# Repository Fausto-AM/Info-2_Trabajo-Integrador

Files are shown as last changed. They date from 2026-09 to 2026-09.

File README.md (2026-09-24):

# Trabajo Práctico Integrador - Máquinas de Estado

Repositorio personal para la entrega del Trabajo Práctico Integrador de Informática II para la UTNFRA.

## Profesores

- Ing. Gustavo Viard.
- Mg. Ing. Damian Ruben Corbalan.

## Generador de Funciones con ESP32

### Resumen

El proyecto consiste en el diseño e implementación de un generador de funciones digital basado en un microcontrolador ESP32-WROOM.

El sistema permite seleccionar la forma de onda y modificar sus principales parámetros mediante un único encoder rotativo con pulsador. La información correspondiente al estado del generador, la función seleccionada y los parámetros configurables se presenta en una pantalla OLED SSD1306 de 128 × 64 píxeles.

La señal de salida es generada digitalmente mediante tablas de consulta (_Look-Up Tables_ [LUT]) y posteriormente convertida a una señal analógica mediante el DAC interno del ESP32. La generación de muestras se realiza a una frecuencia de muestreo de 40 kHz.

El firmware se encuentra organizado en módulos independientes y utiliza una máquina de estados finitos para gestionar la interfaz de usuario y los diferentes modos de operación del generador.

### Objetivos

- Implementar un generador de funciones digital utilizando el DAC interno del ESP32.
- Generar diferentes formas de onda: seno, cuadrada, triangular y sierra.
- Permitir la modificación de frecuencia, amplitud, offset y ciclo de trabajo.
- Permitir la modificación de los parámetros mientras la señal se encuentra siendo generada.
- Implementar una interfaz de usuario utilizando únicamente un encoder rotativo con pulsador.
- Visualizar el estado del sistema y los parámetros configurables mediante una pantalla OLED.
- Implementar una máquina de estados finitos que gestione la navegación y las acciones del usuario.
- Separar las diferentes funciones del firmware en módulos independientes.
- Generar las muestras de salida mediante una frecuencia de muestreo fija de 40 kHz.

### Diseño de la FSM

La interfaz de usuario se implementa mediante una máquina de estados finitos (FSM) contenida en `generator.c` y `generator.h`.

Los eventos producidos por el encoder son:

- `ENC_CW`: giro horario.
- `ENC_CCW`: giro antihorario.
- `ENC_SHORT_PRESS`: pulsación corta.
- `ENC_LONG_PRESS`: pulsación larga.

#### Estados

- `STATE_STANDBY`

    Es el estado inicial de operación del generador.

    La salida se encuentra detenida y el usuario puede desplazarse mediante el encoder entre las siguientes opciones:

    * Parámetros
    * Función
    * RUN

    Una pulsación corta confirma la opción seleccionada.

    Al seleccionar _RUN_, el sistema pasa a `STATE_GENERATING`.

- `STATE_GENERATING`

    En este estado el generador se encuentra funcionando y el DAC recibe las muestras generadas.

    El menú principal pasa a mostrar:

    * Parámetros
    * Función
    * STOP

    Desde este estado también es posible ingresar a los menús de parámetros y selección de función sin detener la generación de la señal.

    Al seleccionar _STOP_, el sistema vuelve a `STATE_STANDBY`.

- `STATE_SELECT_PARAM`

    Permite seleccionar uno de los cuatro parámetros configurables:

    * Frecuencia
    * Amplitud
    * Offset
    * Duty

    Una pulsación corta sobre un parámetro lleva a `STATE_EDIT_PARAM`.

    Una pulsación larga abandona el menú y retorna al estado desde el cual se ingresó.

- `STATE_EDIT_PARAM`

    Permite modificar el parámetro seleccionado mediante el giro del encoder.

    Cada parámetro posee:

    * un valor actual;
    * un límite mínimo;
    * un límite máximo;
    * un tamaño de paso;
    * una función setter encargada de aplicar el nuevo valor.

    Los valores se limitan automáticamente a los rangos definidos en config.h.

    Una pulsación corta o larga finaliza la edición y retorna a `STATE_SELECT_PARAM`.

- `STATE_SELECT_FUNC`

    Permite seleccionar la forma de onda utilizada por el generador:

    * Seno
    * Cuadrada
    * Triangular
    * Sierra

    Una pulsación corta aplica inmediatamente la función seleccionada. Esto permite recorrer las diferentes formas de onda y observar el cambio sin abandonar el menú.

    Una pulsación larga retorna al estado desde el cual se ingresó.

### Descripción de archivos

| Archivo | Responsabilidad |
|---|---|
| main.c | Punto de entrada de la aplicación. Inicializa el sistema y ejecuta el bucle principal de _polling_.
| sys.c/.h | Inicialización general de los módulos y procesamiento de eventos del sistema.
| generator.c/.h | Implementación de la máquina de estados, navegación de menús, selección de parámetros y control `RUN/STOP`.
| encoder.c/.h | Lectura del encoder y del pulsador. Genera los eventos utilizados por la FSM.
| display.c/.h | Control y actualización de la pantalla OLED mediante u8g2 e I2C.
| waveform.c/.h | Generación de las LUT, selección de formas de onda, acumulador de fase y cálculo de muestras.
| dac.c/.h | Abstracción del DAC interno del ESP32 mediante dac_oneshot.
| sample_timer.c/.h | Temporización de la generación de muestras mediante `esp_timer`.
| config.h | Configuración de GPIO, límites de parámetros, frecuencia de muestreo y constantes del sistema.

### Diagrama de la Máquina de Estado

Diagrama de la Máquina de Estado

### Esquemático

Esquemático

### PCB Finalizado

PCB

### Proyecto Funcionando

Proyecto en Funcionamiento

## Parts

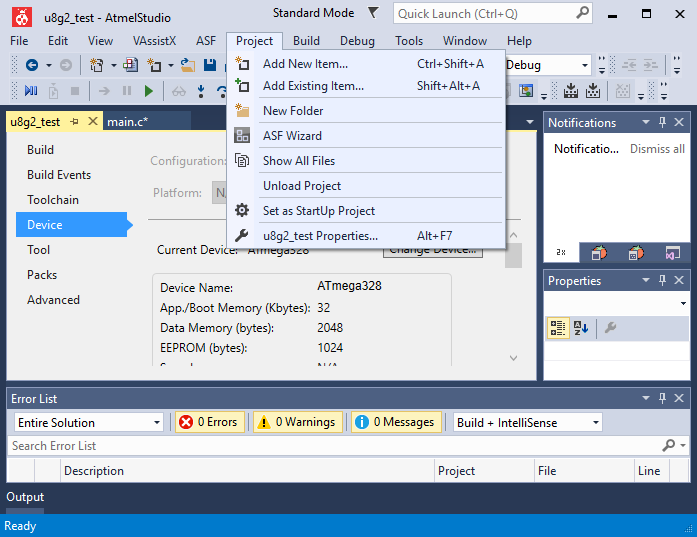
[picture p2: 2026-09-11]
Signal_Generator/components/u8g2/sys/avr/as7/as7_006.png

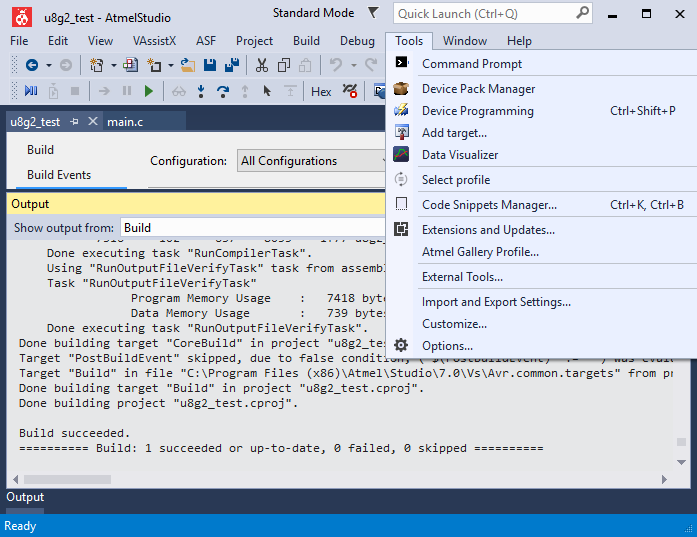
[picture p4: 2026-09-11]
Signal_Generator/components/u8g2/sys/avr/as7/as7_012.png

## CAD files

Signal_Generator/components/u8g2/sys/arduino/u8g2_full_buffer/SwitchBox/board.dxf
60
40
52
8
24
80
30
32
25
100
190
4
12
6
14

Signal_Generator/components/u8g2/sys/arm/stm32l031x6/clock_2.dxf
65
Draufsicht
Vorderansicht
von unten
von rechts
von links
14
30
32
35
75
55
10
12
16
11
22
34
28
29
18
93
19
43
15
68
60
57
150
Holzbohrer: 2.5, 8, 10, 12, 16, 32mm
8
7
6
2.5mm

Signal_Generator/components/u8g2/sys/arm/stm32l031x6/clock.dxf
65
32
28
16
Draufsicht
Vorderansicht
von unten
von rechts
von links
14
6
45
60
30
20
8
35
75
55
10
12

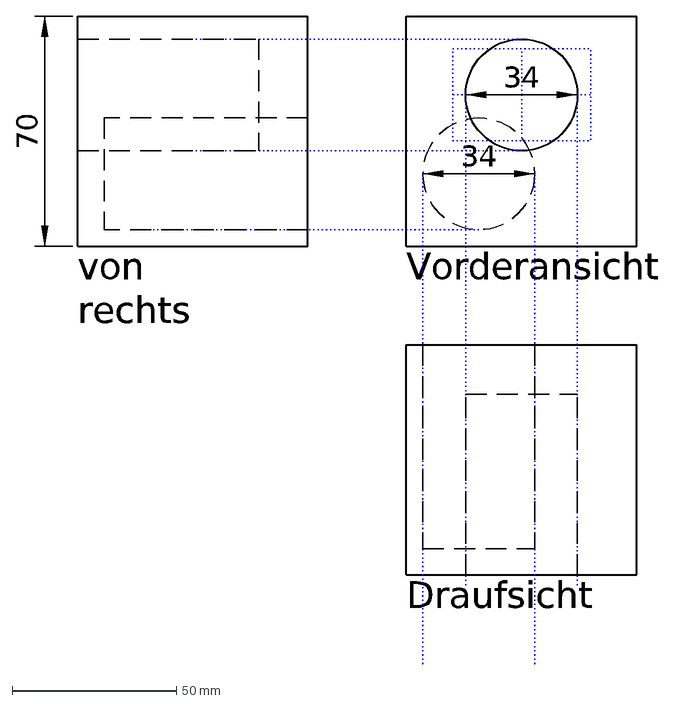
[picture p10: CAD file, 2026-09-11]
Signal_Generator/components/u8g2/sys/arm/stm32l031x6/clock_cube.dxf
Draufsicht
Vorderansicht
von rechts
70
34

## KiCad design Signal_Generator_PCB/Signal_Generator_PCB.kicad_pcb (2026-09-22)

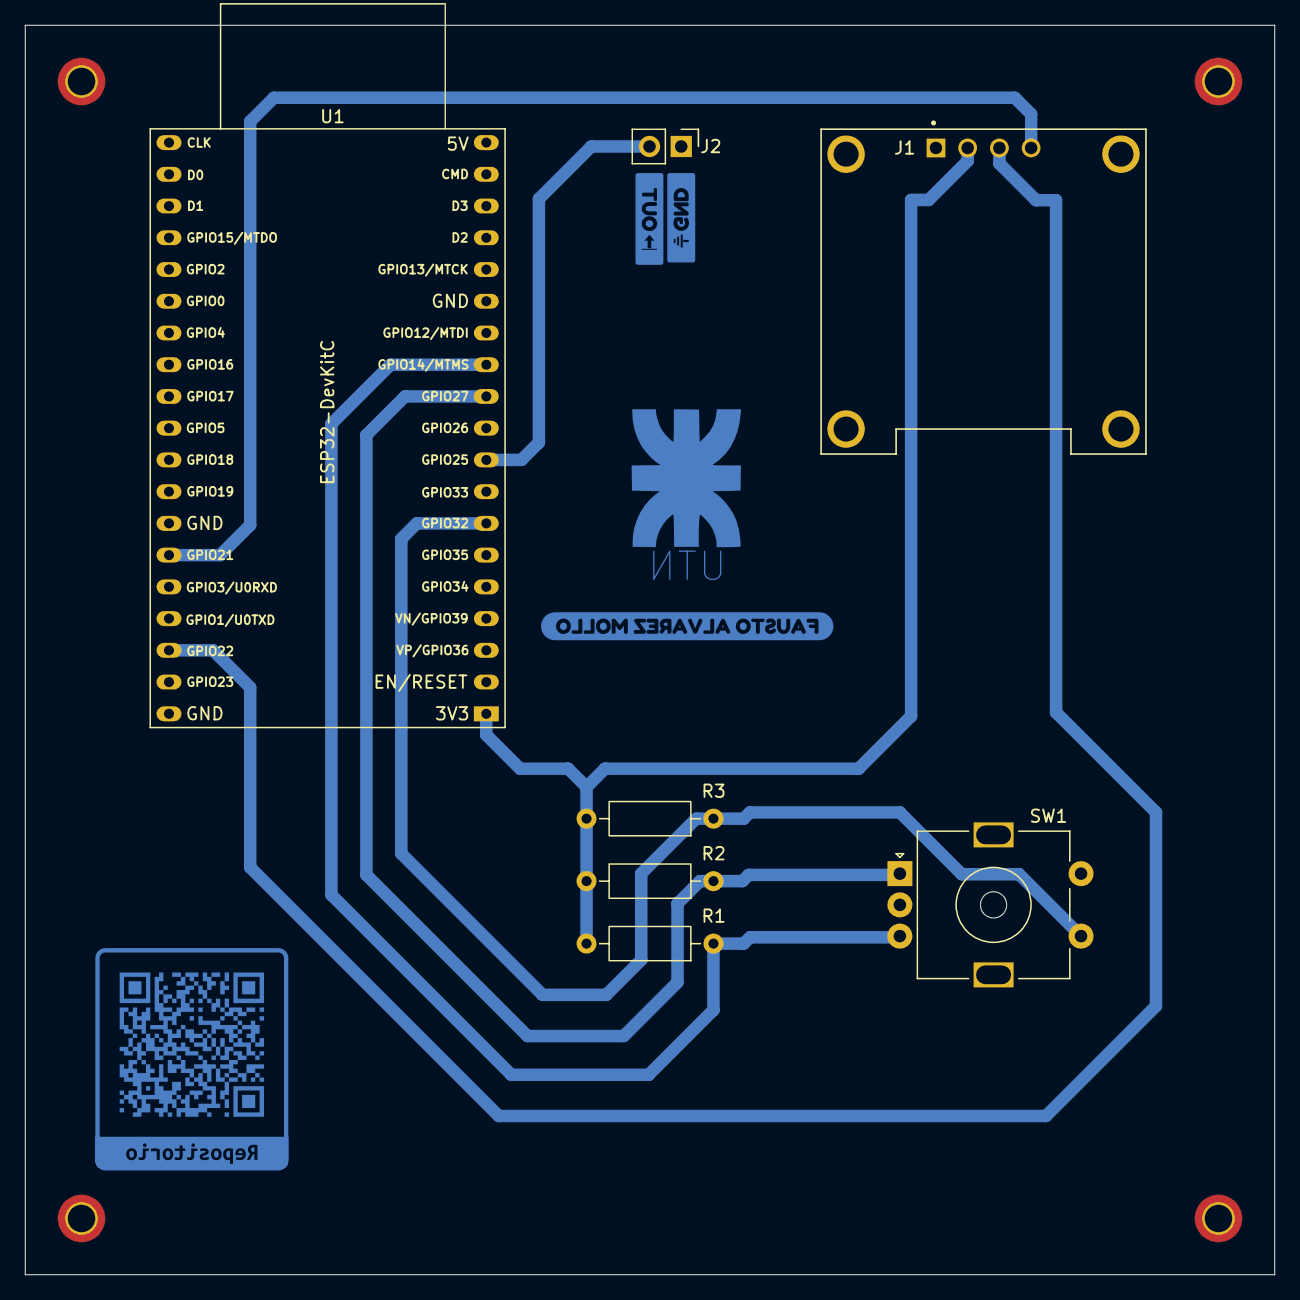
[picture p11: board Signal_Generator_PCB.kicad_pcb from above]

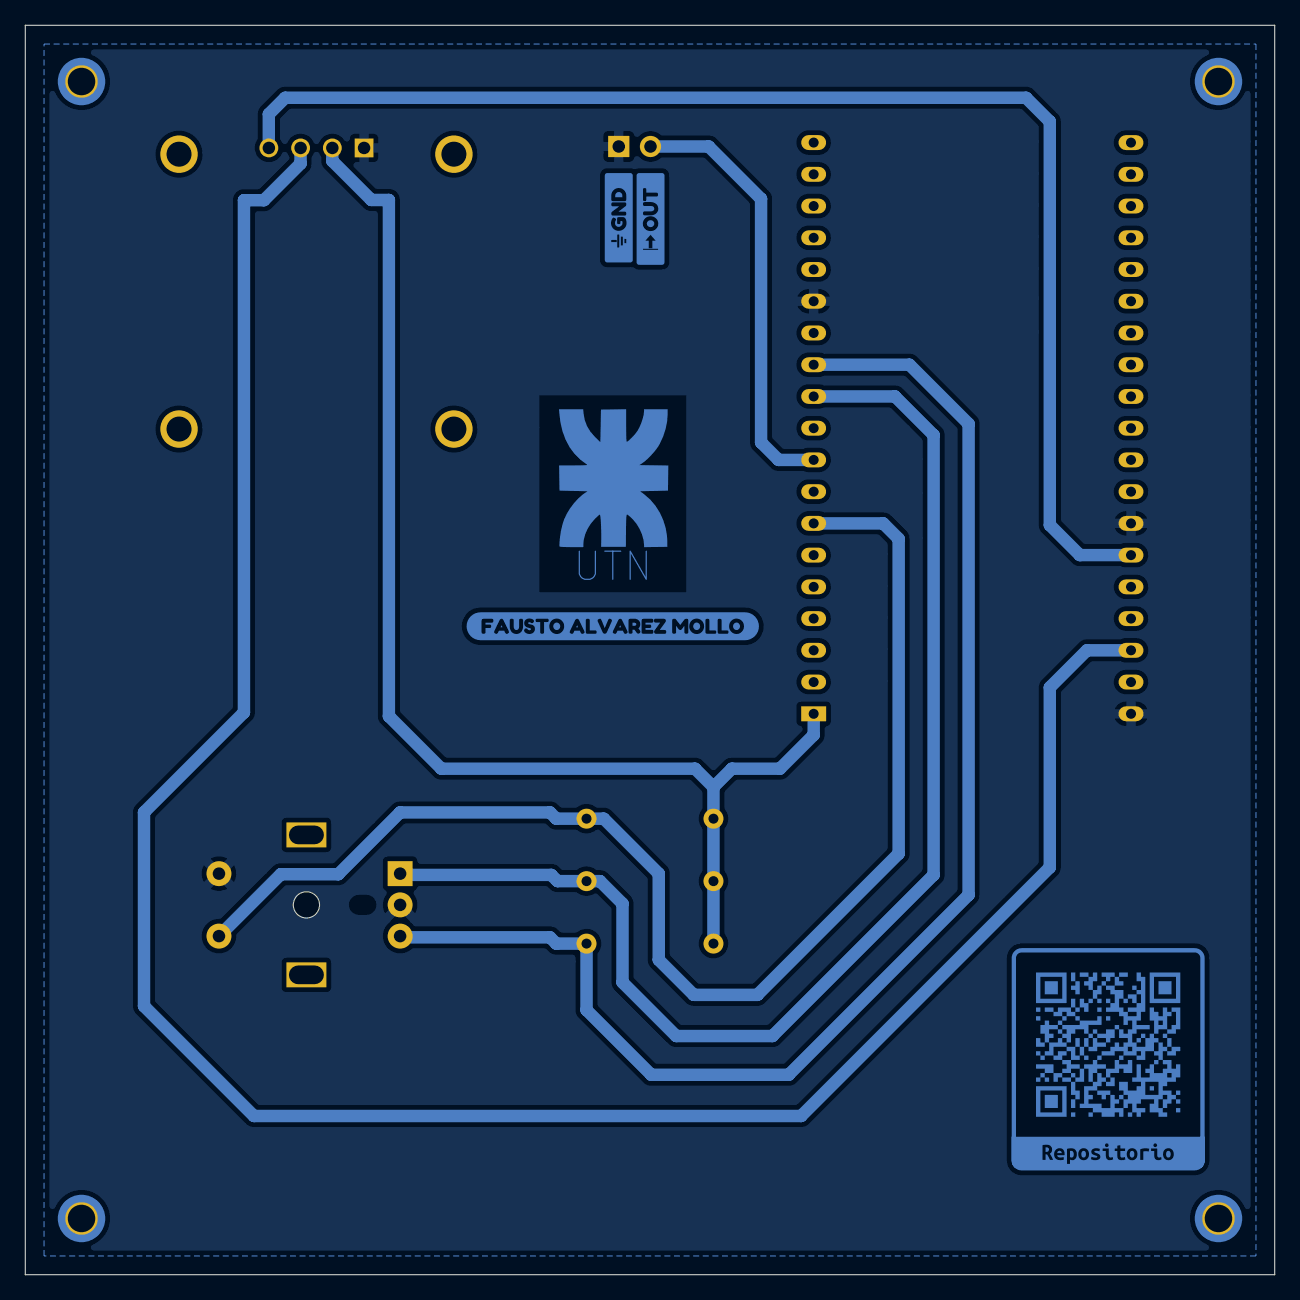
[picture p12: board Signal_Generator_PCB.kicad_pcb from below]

Board: 2 copper layers, 100.0 x 100.0 mm, 11 parts (4 on the bottom side), 8 nets.

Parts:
J1: OLED Screen; MODULE_DM-OLED096-636
J2: Conn_01x02; PinHeader_1x02_P2.54mm_Vertical
R1, R2, R3: 10k; R_Axial_DIN0207_L6.3mm_D2.5mm_P10.16mm_Horizontal
SW1: Rotary Encoder with Switch; RotaryEncoder_Alps_EC11E-Switch_Vertical_H20mm_MountingHoles
U1: ESP32-DevKitC
kobee-studio-6AAF5AC9: Kobee Studio; kobee-studio-6AAF5ABC
kobee-studio-6AAF54B1: Kobee Studio; kobee-studio-6AAF52F9
kobee-studio-6AAF59F9: Kobee Studio; kobee-studio-6AAF59EB
kobee-studio-6AAF543E: Kobee Studio; kobee-studio-6AAF5432

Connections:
+3.3V: J1.2 (VDD), R1.2, R2.2, R3.2, U1.1 (3V3)
/GPIO14: R1.1, SW1.B, U1.12 (MTMS/GPIO14/ADC2_CH6)
/GPIO21: J1.4 (SDA), U1.33 (GPIO21)
/GPIO22: J1.3 (SCK), U1.36 (GPIO22)
/GPIO25: J2.1, U1.9 (DAC_1/ADC2_CH8/GPIO25)
/GPIO27: R2.1, SW1.A, U1.11 (ADC2_CH7/GPIO27)
/GPIO32: R3.1, SW1.S1, U1.7 (32K_XP/GPIO32/ADC1_CH4)
GND: J1.1 (GND), J2.2, SW1.C, SW1.S2, U1.14 (GND), U1.32 (GND), U1.38 (GND)

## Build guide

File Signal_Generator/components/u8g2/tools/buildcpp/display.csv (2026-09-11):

# 1. device name
# 2. pinset
# 3. constructor name w/o prefix
u8x8_d_ssd1306_128x64_noname | 4WSWSPI | SSD1306_128X64_4W_SW_SPI
u8x8_d_ssd1306_128x64_noname | 4WHWSPI | SSD1306_128X64_4W_HW_SPI
u8x8_d_ssd1306_128x64_noname | 3WSWSPI | SSD1306_128X64_3W_SW_SPI
u8x8_d_ssd1306_128x64_noname | SSDSWI2C | SSD1306_128X64_SW_I2C
u8x8_d_ssd1306_128x64_noname | 6800 | SSD1306_128X64_6800
u8x8_d_ssd1306_128x64_noname | 8080 | SSD1306_128X64_8080

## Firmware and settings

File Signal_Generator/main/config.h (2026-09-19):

#ifndef CONFIG_H
#define CONFIG_H

#include <stdint.h>

// GPIO definitions
#define PIN_SDA       21
#define PIN_SCL       22
#define PIN_DAC       25
#define PIN_ENC_A     27
#define PIN_ENC_B     14
#define PIN_ENC_BTTN  32


// OLED Display parameters
#define OLED_ADDR     0x3C
#define OLED_WIDTH    128
#define OLED_HEIGHT   64


// Waveform generation parameters
#define LUT_SIZE      256
#define SAMPLE_RATE   40000.0f
#define BASE_FREQ     1000.0f
#define BASE_AMP_VPP  1.65f
#define BASE_OFFSET   0.0f
#define BASE_DUTY     0.5f
#define MIN_FREQ      1.0f
#define MAX_FREQ      5000.0f
#define MIN_AMP_VPP   0.1f
#define MAX_AMP_VPP   3.3f
#define MIN_OFFSET   -3.0f
#define MAX_OFFSET    3.3f
#define MIN_DUTY      0.0f
#define MAX_DUTY      1.0f

// General Parameters
#define DAC_MAX_VALUE 255
#define BUTTON_LONG_PRESS_MS 500
#define BUTTON_DEBOUNCE_MS   25
#define ENCODER_STEPS_PER_DETENT  2

#endif

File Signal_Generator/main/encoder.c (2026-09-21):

#include "encoder.h"
#include "esp_timer.h"
#include "esp_log.h"

static const char *TAG = "ENCODER";

static volatile int enc_count = 0;

static volatile uint8_t last_ab_state = 0;

static int last_count = 0;

static uint64_t btn_press_start = 0;

static int btn_pressed = 0;
static int raw_pressed_prev = 0;
static uint64_t raw_change_ms = 0;
static const int8_t qdec_table[16] = {
     0, -1,  1,  0,
     1,  0,  0, -1,
    -1,  0,  0,  1,
     0,  1, -1,  0
};

void IRAM_ATTR encoder_isr(void *arg)
{
    (void)arg;

    uint8_t a = (uint8_t)gpio_get_level(PIN_ENC_A);
    uint8_t b = (uint8_t)gpio_get_level(PIN_ENC_B);

    uint8_t new_state = (a << 1) | b;

    uint8_t index = (last_ab_state << 2) | new_state;

    enc_count += qdec_table[index];

    last_ab_state = new_state;
}

void encoder_init(void)
{
    gpio_config_t encoder_config = {

        .pin_bit_mask = (1ULL << PIN_ENC_A) | (1ULL << PIN_ENC_B),

        .mode = GPIO_MODE_INPUT,

        .pull_up_en = GPIO_PULLUP_DISABLE,

        .pull_down_en = GPIO_PULLDOWN_DISABLE,

        .intr_type = GPIO_INTR_DISABLE
    };

    ESP_ERROR_CHECK(gpio_config(&encoder_config));

    gpio_config_t button_config = {

        .pin_bit_mask =
            (1ULL << PIN_ENC_BTTN),

        .mode = GPIO_MODE_INPUT,

        .pull_up_en = GPIO_PULLUP_ENABLE,

        .pull_down_en = GPIO_PULLDOWN_DISABLE,

        .intr_type = GPIO_INTR_DISABLE
    };

    ESP_ERROR_CHECK(gpio_config(&button_config));

    ESP_ERROR_CHECK(gpio_set_intr_type(PIN_ENC_A, GPIO_INTR_ANYEDGE));

    ESP_ERROR_CHECK(gpio_set_intr_type(PIN_ENC_B, GPIO_INTR_ANYEDGE));

    ESP_ERROR_CHECK(gpio_install_isr_service(0));

    ESP_ERROR_CHECK(gpio_isr_handler_add(PIN_ENC_A, encoder_isr, NULL));

    ESP_ERROR_CHECK(gpio_isr_handler_add(PIN_ENC_B, encoder_isr, NULL));

    last_ab_state = ((uint8_t)gpio_get_level(PIN_ENC_A) << 1) | (uint8_t)gpio_get_level(PIN_ENC_B);

    ESP_LOGI(TAG, "Encoder initialized (A=%d B=%d BTN=%d)", PIN_ENC_A, PIN_ENC_B, PIN_ENC_BTTN);
}

encoder_t encoder_get_event(void)
{
    encoder_t event = ENC_NONE;

    uint64_t now_ms = esp_timer_get_time() / 1000;

    int raw_pressed =
        (gpio_get_level(PIN_ENC_BTTN) == 0);

    if (raw_pressed != raw_pressed_prev) {

        raw_pressed_prev = raw_pressed;
        raw_change_ms = now_ms;
    }

    if ((raw_pressed != btn_pressed) &&
        ((now_ms - raw_change_ms) >= BUTTON_DEBOUNCE_MS)) {

        btn_pressed = raw_pressed;

        if (btn_pressed) {

            btn_press_start = now_ms;

        } else {

            uint64_t duration =
                now_ms - btn_press_start;


            if (duration >= BUTTON_LONG_PRESS_MS) {

                event = ENC_LONG_PRESS;

            } else {

                event = ENC_SHORT_PRESS;
            }

            ESP_LOGI(TAG, "Button event: %s (held %llu ms)", (event == ENC_LONG_PRESS) ? "LONG_PRESS" : "SHORT_PRESS", (unsigned long long)duration);
        }

        return event;
    }

    if (enc_count - last_count >= ENCODER_STEPS_PER_DETENT) {

        event = ENC_CW;

        last_count += ENCODER_STEPS_PER_DETENT;

        ESP_LOGD(TAG, "Rotation event: CW (count=%d)", enc_count);

    } else if (enc_count - last_count <= -ENCODER_STEPS_PER_DETENT) {

        event = ENC_CCW;

        last_count -= ENCODER_STEPS_PER_DETENT;

        ESP_LOGD(TAG, "Rotation event: CCW (count=%d)", enc_count);
    }

    return event;
}

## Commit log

2026-08-25 docs: Actualizo el README.md
2026-08-28 docs(Assets): Creo el directorio de Assets
2026-08-29 docs(Assets): Modifico el Diagrama de Estados y Transiciones
2026-08-29 docs(README): Modifico el README.md
2026-09-03 docs(README): Actualizo el README.md
2026-09-03 docs(LICENSE): Añado la licencia de Open Source
2026-09-04 feat(PCB): Creación del Esquemático
    [Signal_Generator_PCB.kicad_pcb, Signal_Generator_PCB.kicad_sch]
2026-09-05 feat:(develop) Añado la primer versión del esquemático y PCB
    [Signal_Generator_PCB.kicad_pcb, Signal_Generator_PCB.kicad_sch, temp-freerouting.dsn]
2026-09-05 docs(Assets): Error en el Esquemático
2026-09-05 docs(Assets): Corrigo en el README.md
2026-09-07 feat(Signal_Generator): Añado los header files.
    [Signal_Generator_PCB.kicad_pcb, Signal_Generator_PCB.kicad_sch]
2026-09-08 feat(Signal_Generator): Termino la primer versión
2026-09-08 feat(Signal_Generator_PCB): v02
    [Signal_Generator_PCB.kicad_pcb, Signal_Generator_PCB.kicad_sch]
2026-09-11 feat(Signal_Generator): Primer Versión Parcial del Código
    [Signal_Generator_PCB.kicad_pcb, board.dxf, clock.dxf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]
2026-09-11 docs(README.md): Cambio en la escritura
2026-09-11 docs(README.md): Actualizo el Esquemático
2026-09-19 feat(PCB): Cambios en la configuración de la PCB.
    [Signal_Generator_PCB.kicad_pcb, Signal_Generator_PCB.kicad_sch]
2026-09-19 fix(Signal_Generator): Aumento el sample rate para que la onda no quede tan discretizada.
    [config.h]
2026-09-19 docs(): Actualizo el Diagrama de Estados y Transiciones
2026-09-19 fix(): Me equivoqué con el Nombre
2026-09-19 docs(Readme): Actualizo el esquemático
2026-09-19 docs(Readme): Actualizo datos en el Readme
2026-09-21 feat(PCB): Redistribuyo y embellezco la placa
    [Signal_Generator_PCB.kicad_pcb]
2026-09-21 docs(README.md): Mejoro un poco la escritura de la memoria descriptiva.
2026-09-21 remove(.vscode): No debería de estar acá.
2026-09-22 style(PCB): Cambio el Logo de la Universidad
    [Signal_Generator_PCB.kicad_pcb]
2026-09-24 docs(Readme.md): Cambio un poco la escritura y añado.
